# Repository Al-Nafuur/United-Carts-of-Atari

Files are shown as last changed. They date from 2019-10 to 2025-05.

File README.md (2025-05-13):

# Atari 2600 PlusCart

## Description
the Atari 2600 PlusCart ist based on Robin Edwards Unocart-2600 (https://github.com/robinhedwards/UnoCart-2600) and the extensions of Christian Speckner's (DirtyHairy) fork (https://github.com/DirtyHairy/UnoCart-2600). The PlusCart has no SD-Card, but an ESP8266 to connect to a local WiFi Network and the Internet.
The PlusCart downloads the ROM-files from an Server in the Internet called the "PlusStore". The way this is done is similar to the way the Unocart-2600 loads ROMs from the FAT filesystem on the SD-card, while the VCS is performing a waitroutine in his RAM.

## PlusROM
Additionally the PlusCart has one more interesting feature. It offers **internet access** to the ROM Developers, these functions are called "[PlusROM](http://pcart.firmaplus.de/pico/?PlusROM)". Examples for PlusROMs can be found in the [PlusROM-Hacks Repository](https://github.com/Al-Nafuur/PlusROM-Hacks) on Github.

## [Documentation](http://pcart.firmaplus.de/pico/)
More information and documentation can be found at the [PlusCart website](http://pcart.firmaplus.de/pico/)

Copyright:

(c) Firmaplus(+) Ltd.

Dipl.Ing.(FH) Wolfgang Stubig

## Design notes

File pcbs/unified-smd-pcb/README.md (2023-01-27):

Unified PlusCart UnoCart SMD PCB
===============

based on Randy Glenn's Unocart2600 PCB 
https://github.com/rglenn/unocart2600-pcb

migrated to KiCAD 6 and PlusCart WiFi module ESP8266 added by Wolfgang Stubig

Licensed under CERN OHL 1.2. See LICENSE.txt for more information.

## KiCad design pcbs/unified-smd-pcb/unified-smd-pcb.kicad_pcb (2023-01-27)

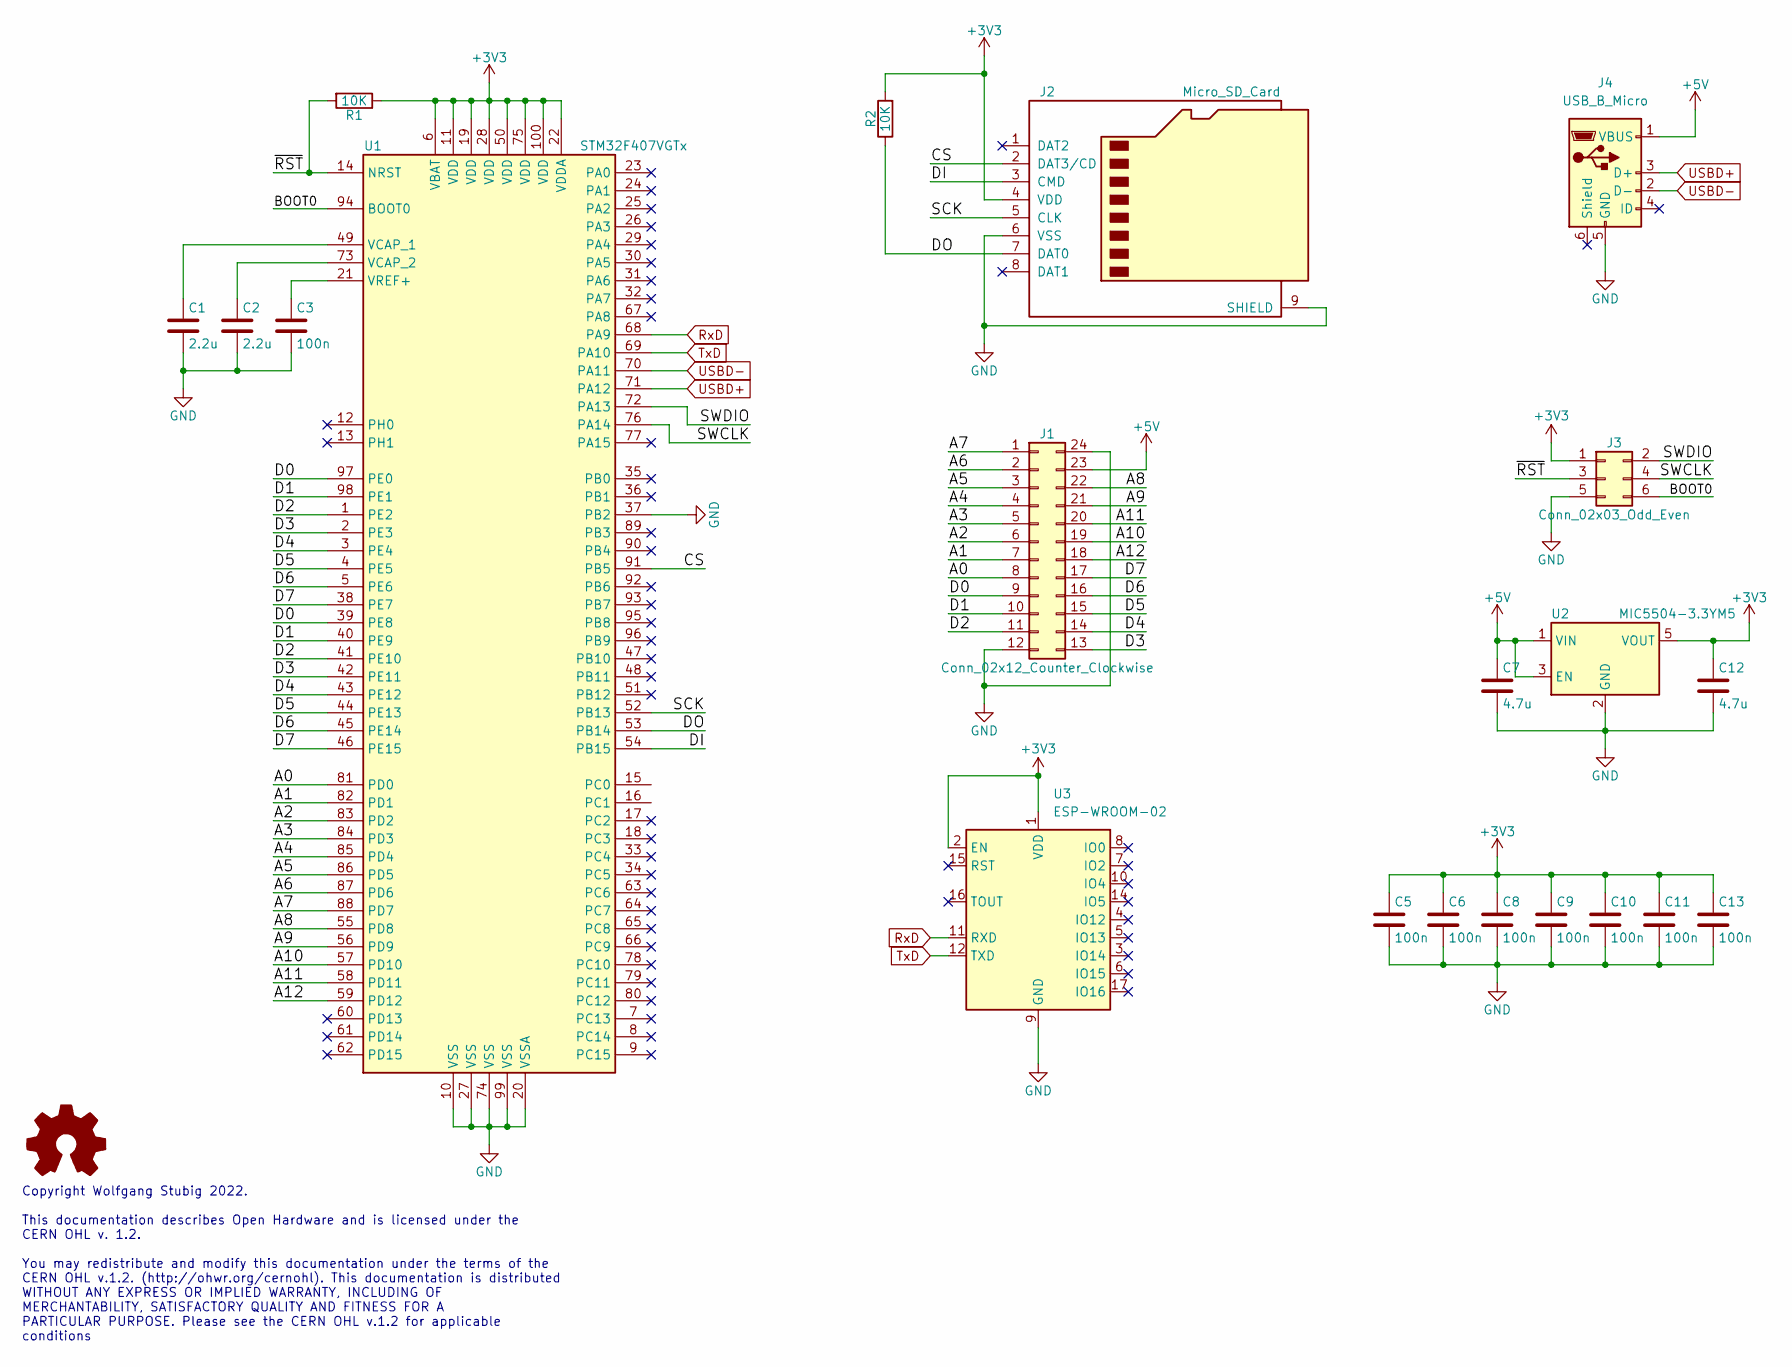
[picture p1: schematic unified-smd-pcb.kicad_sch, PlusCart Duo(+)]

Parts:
C1, C2: 2.2u; C_0603_1608Metric
C3, C5, C6, C8, C9, C10, C11, C13: 100n; C_0603_1608Metric
C7, C12: 4.7u; C_0805_2012Metric
J1: Conn_02x12_Counter_Clockwise; 2600-CARTRIDGE
J2: Micro_SD_Card; microSD_HRO_TF_01A
J3: Conn_02x03_Odd_Even; Tag-Connect_TC2030-IDC-NL_2x03_P1.27mm_Vertical
J4: USB_B_Micro; USB_Micro-B_Molex_47346-0001
R1, R2: 10K; R_0603_1608Metric
U1: STM32F407VGTx; LQFP-100_14x14mm_P0.5mm
U2: MIC5504-3.3YM5; SOT-23-5
U3: ESP-WROOM-02

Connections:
+3V3: C5.1, C6.1, C8.1, C9.1, C10.1, C11.1, C12.1, C13.1, J2.4 (VDD), J3.1, R1.1, R2.2, U1.6 (VBAT), U1.11 (VDD), U1.19 (VDD), U1.22 (VDDA), U1.28 (VDD), U1.50 (VDD), U1.75 (VDD), U1.100 (VDD), U2.5 (VOUT), U3.1 (VDD), U3.2 (EN)
+5V: C7.1, J1.23, J4.1 (VBUS), U2.1 (VIN), U2.3 (EN)
/A0: J1.8, U1.81 (PD0)
/A1: J1.7, U1.82 (PD1)
/A2: J1.6, U1.83 (PD2)
/A3: J1.5, U1.84 (PD3)
/A4: J1.4, U1.85 (PD4)
/A5: J1.3, U1.86 (PD5)
/A6: J1.2, U1.87 (PD6)
/A7: J1.1, U1.88 (PD7)
/A8: J1.22, U1.55 (PD8)
/A9: J1.21, U1.56 (PD9)
/A10: J1.19, U1.57 (PD10)
/A11: J1.20, U1.58 (PD11)
/A12: J1.18, U1.59 (PD12)
/BOOT0: J3.6, U1.94 (BOOT0)
/CS: J2.2 (DAT3/CD), U1.91 (PB5)
/D0: J1.9, U1.39 (PE8), U1.97 (PE0)
/D1: J1.10, U1.40 (PE9), U1.98 (PE1)
/D2: J1.11, U1.1 (PE2), U1.41 (PE10)
/D3: J1.13, U1.2 (PE3), U1.42 (PE11)
/D4: J1.14, U1.3 (PE4), U1.43 (PE12)
/D5: J1.15, U1.4 (PE5), U1.44 (PE13)
/D6: J1.16, U1.5 (PE6), U1.45 (PE14)
/D7: J1.17, U1.38 (PE7), U1.46 (PE15)
/DI: J2.3 (CMD), U1.54 (PB15)
/DO: J2.7 (DAT0), R2.1, U1.53 (PB14)
/SCK: J2.5 (CLK), U1.52 (PB13)
/SWCLK: J3.4, U1.76 (PA14)
/SWDIO: J3.2, U1.72 (PA13)
/~RST: J3.3, R1.2, U1.14 (NRST)
GND: C1.2, C2.2, C3.2, C5.2, C6.2, C7.2, C8.2, C9.2, C10.2, C11.2, C12.2, C13.2, J1.12, J1.24, J2.6 (VSS), J2.9 (SHIELD), J3.5, J4.5 (GND), U1.10 (VSS), U1.20 (VSSA), U1.27 (VSS), U1.37 (PB2), U1.74 (VSS), U1.99 (VSS), U2.2 (GND), U3.9 (GND), U3.13 (GND), U3.18 (GND), U3.19 (GND)
unnamed: C1.1, U1.49 (VCAP_1)
unnamed: C2.1, U1.73 (VCAP_2)
unnamed: C3.1, U1.21 (VREF+)
RxD: U1.68 (PA9), U3.11 (RXD)
TxD: U1.69 (PA10), U3.12 (TXD)
USBD+: J4.3 (D+), U1.71 (PA12)
USBD-: J4.2 (D-), U1.70 (PA11)

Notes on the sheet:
Copyright Wolfgang Stubig 2022. This documentation describes Open Hardware and is licensed under the CERN OHL v. 1.2. You may redistribute and modify this documentation under the terms of the CERN OHL v.1.2. (http://ohwr.org/cernohl). This documentation is distributed WITHOUT ANY EXPRESS OR IMPLIED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

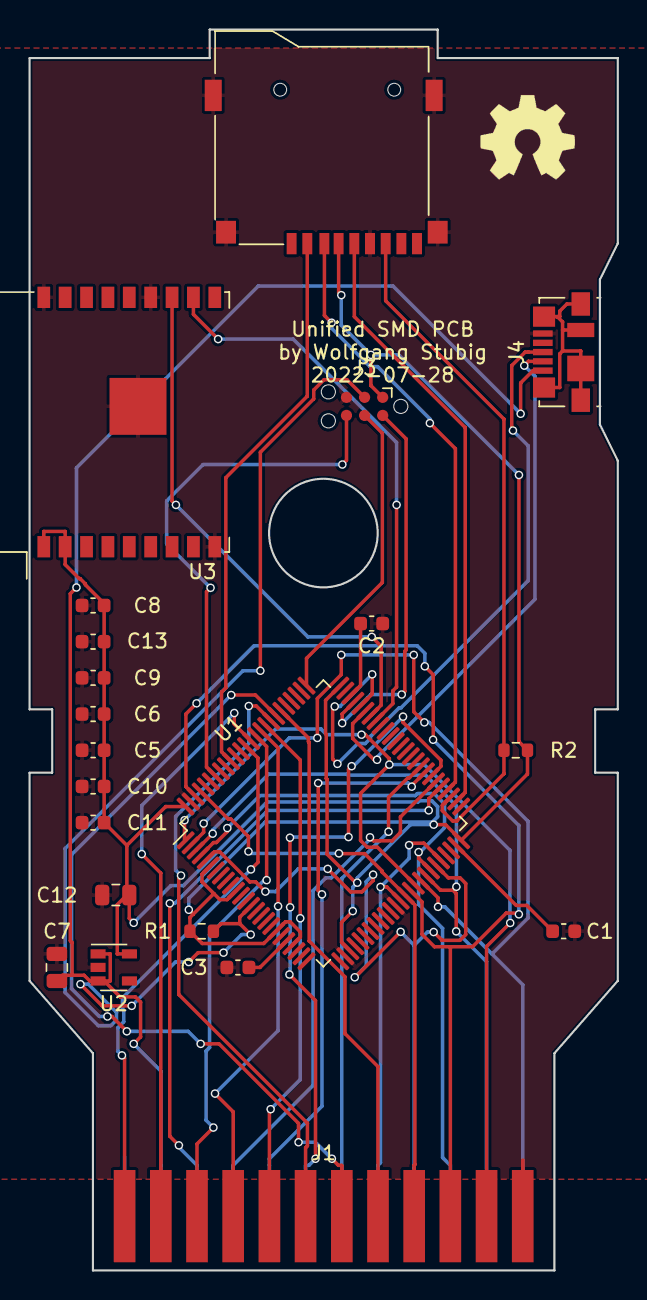
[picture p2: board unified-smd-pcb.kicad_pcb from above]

Board: 2 copper layers, 41.3 x 87.1 mm, 21 parts (0 on the bottom side), 39 nets.

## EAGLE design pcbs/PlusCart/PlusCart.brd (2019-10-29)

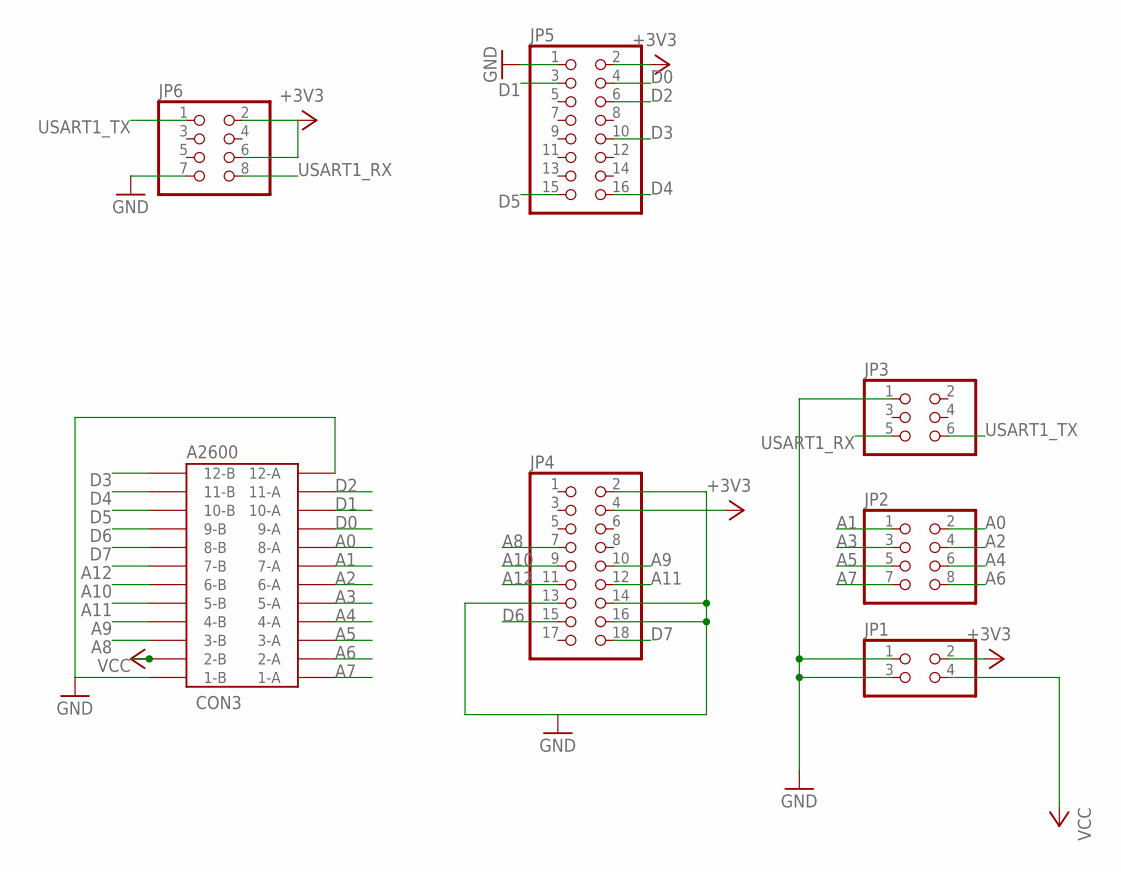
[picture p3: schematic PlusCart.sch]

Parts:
CON3: A2600; 24PINEDGE-254MM
JP1: PINHD-2X2; 2X02
JP2, JP6: PINHD-2X4; 2X04
JP3: PINHD-2X3; 2X03
JP4: PINHD-2X9; 2X09
JP5: PINHD-2X8; 2X08

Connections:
+3V3: JP1.2, JP4.4, JP5.2, JP6.2, JP6.6
A0: CON3.8-A, JP2.2
A1: CON3.7-A, JP2.1
A2: CON3.6-A, JP2.4
A3: CON3.5-A, JP2.3
A4: CON3.4-A, JP2.6
A5: CON3.3-A, JP2.5
A6: CON3.2-A, JP2.8
A7: CON3.1-A, JP2.7
A8: CON3.3-B, JP4.7
A9: CON3.4-B, JP4.10
A10: CON3.6-B, JP4.9
A11: CON3.5-B, JP4.12
A12: CON3.7-B, JP4.11
D0: CON3.9-A, JP5.4
D1: CON3.10-A, JP5.3
D2: CON3.11-A, JP5.6
D3: CON3.12-B, JP5.10
D4: CON3.11-B, JP5.16
D5: CON3.10-B, JP5.15
D6: CON3.9-B, JP4.15
D7: CON3.8-B, JP4.18
GND: CON3.1-B, CON3.12-A, JP1.1, JP1.3, JP3.1, JP4.2, JP4.13, JP4.14, JP4.16, JP5.1, JP6.7
USART1_RX: JP3.5, JP6.8
USART1_TX: JP3.6, JP6.1
VCC: CON3.2-B, JP1.4

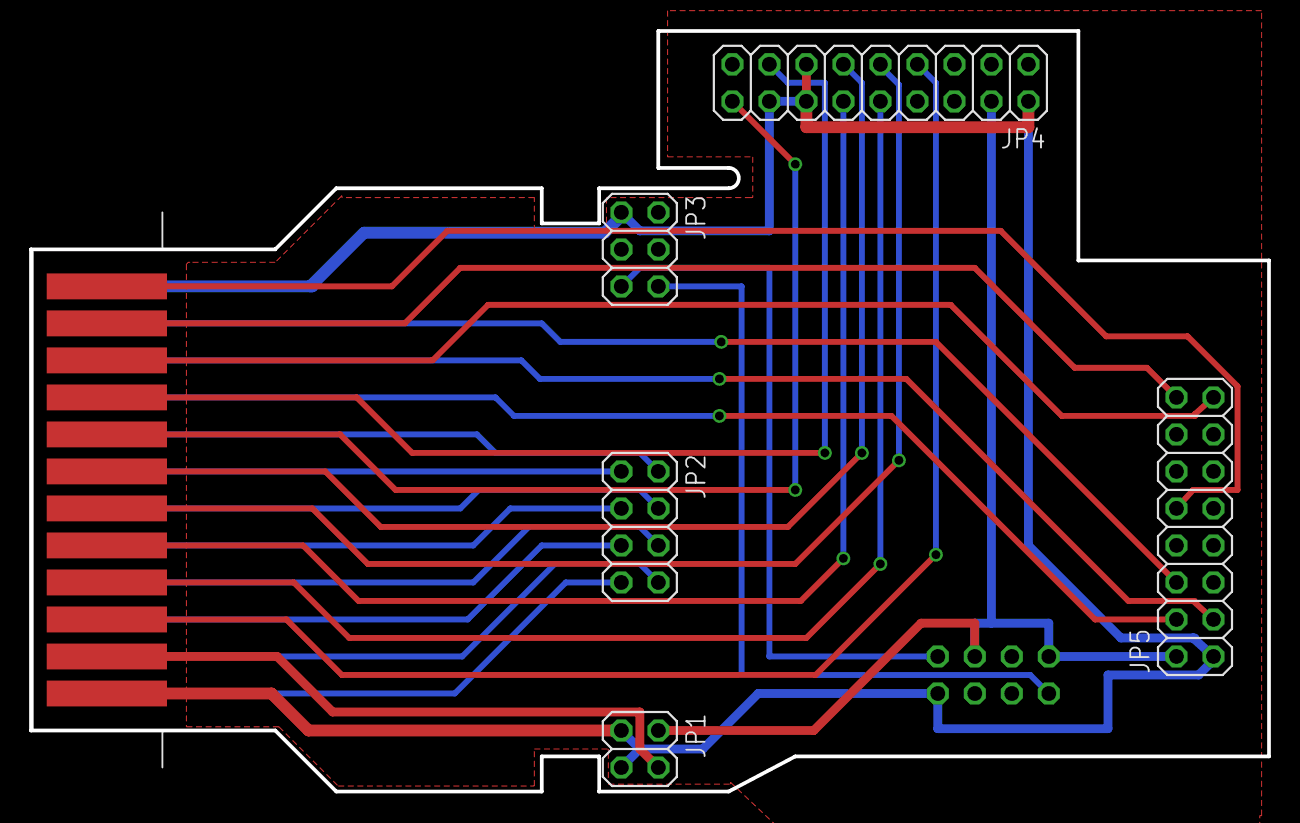
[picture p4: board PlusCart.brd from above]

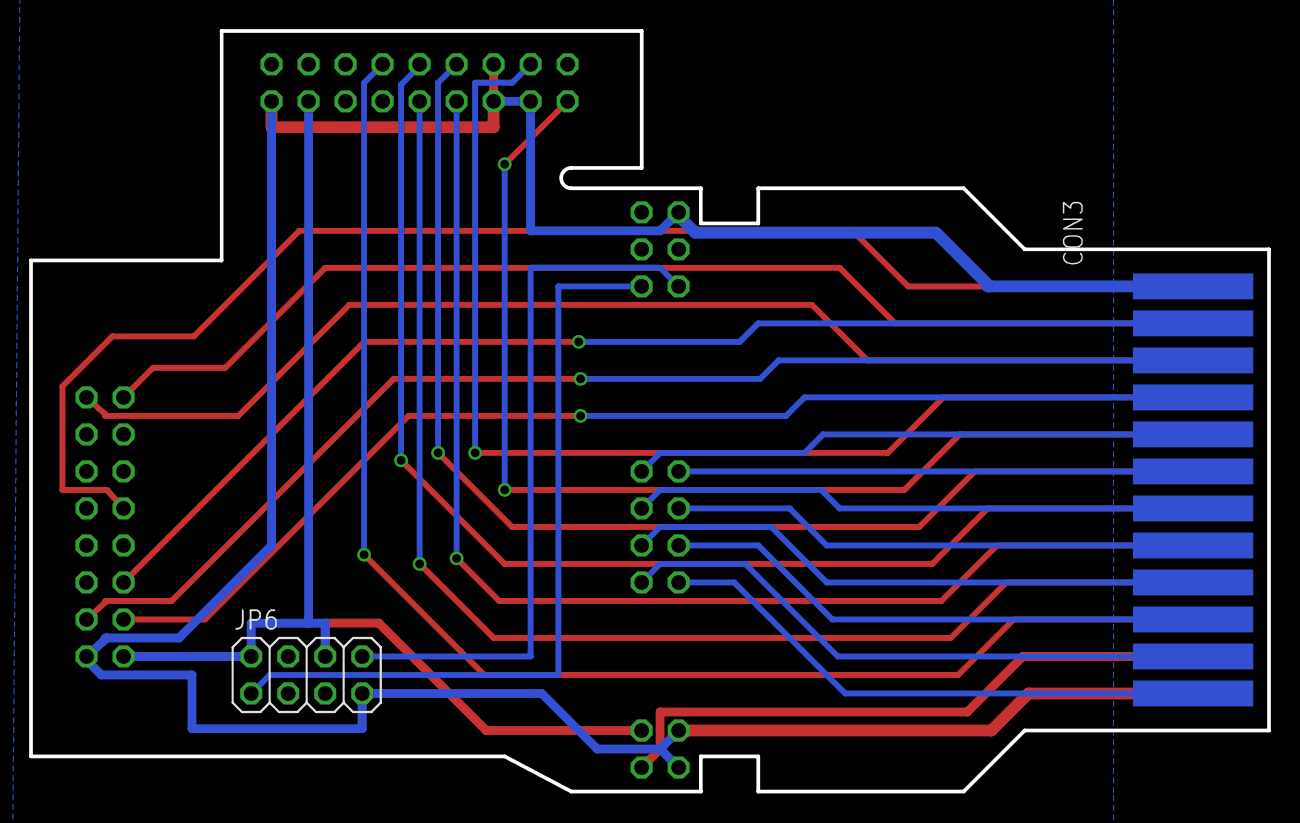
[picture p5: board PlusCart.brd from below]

Board: 2 copper layers, 85.0 x 52.2 mm, 7 parts (2 on the bottom side), 26 nets.

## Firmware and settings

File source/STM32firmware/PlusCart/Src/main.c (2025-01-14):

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
/* Includes ------------------------------------------------------------------*/
#include "main.h"

/* USER CODE BEGIN Includes */
#include <stdlib.h>
#include <stdio.h>
#include <ctype.h>
#include <string.h>

#include "global.h"
#include "font.h"
#if USE_WIFI
#include "esp8266.h"
#endif
#if USE_SD_CARD
#include "fatfs.h"
#endif

#include "stm32_udid.h"
#include "flash.h"
#include "cartridge_io.h"
#include "cartridge_firmware.h"
#include "cartridge_emulation_ACE.h"
#include "cartridge_emulation_ar.h"
#include "cartridge_emulation_ELF.h"
#include "cartridge_detection.h"
#include "cartridge_emulation.h"
#include "cartridge_emulation_df.h"
#include "cartridge_emulation_bf.h"
#include "cartridge_emulation_sb.h"
#include "cartridge_emulation_3F.h"


void generate_udid_string(void);

void truncate_curPath(/*uint8_t count*/);

/* USER CODE END Includes */

/* USER CODE BEGIN PTD */

typedef struct {
	enum cart_base_type base_type;
	bool withSuperChip;
	bool withPlusFunctions;
	bool uses_ccmram;
	bool uses_systick;
	uint32_t flash_part_address;
} CART_TYPE;

typedef struct {
	const char *ext;
	CART_TYPE cart_type;
} EXT_TO_CART_TYPE_MAP;

/* USER CODE END PTD */

/* USER CODE BEGIN PD */

const EXT_TO_CART_TYPE_MAP ext_to_cart_type_map[]__attribute__((section(".flash01"))) = {
	{"ROM",  { base_type_None,    false, false, false, false }},
	{"BIN",  { base_type_None,    false, false, false, false }},
	{"A26",  { base_type_None,    false, false, false, false }},
	{"2K",   { base_type_2K,      false, false, false, false }},
	{"4K",   { base_type_4K,      false, false, false, false }},
	{"4KS",  { base_type_4K,      true,  false, false, false }},
	{"F8",   { base_type_F8,      false, false, false, false }},
	{"F6",   { base_type_F6,      false, false, false, false }},
	{"F4",   { base_type_F4,      false, false, false, false }},
	{"F8S",  { base_type_F8,      true,  false, false, false }},
	{"F6S",  { base_type_F6,      true,  false, false, false }},
	{"F4S",  { base_type_F4,      true,  false, false, false }},
	{"FE",   { base_type_FE,      false, false, false, false }},
	{"3F",   { base_type_3F,      false, false, false, false }},
	{"3E",   { base_type_3E,      false, false, false, false }},
	{"E0",   { base_type_E0,      false, false, false, false }},
	{"084",  { base_type_0840,    false, false, false, false }},
	{"CV",   { base_type_CV,      false, false, false, false }},
	{"EF",   { base_type_EF,      false, false, false, false }},
	{"EFS",  { base_type_EF,      true,  false, false, false }},
	{"F0",   { base_type_F0,      false, false, false, false }},
	{"FA",   { base_type_FA,      false, false, false, false }},
	{"FA2",  { base_type_FA2,     false, false, false, false }},
	{"E7",   { base_type_E7,      false, false, false, false }},
	{"DPC",  { base_type_DPC,     false, false, true,  true  }},
	{"AR",   { base_type_AR,      false, false, false, false }},
	{"BF",   { base_type_BF,      false, false, true,  false }},
	{"BFS",  { base_type_BFSC,    false, false, true,  false }},
	{"ACE",  { base_type_ACE,     false, false, false, false }},
	{"WD",   { base_type_PP,      false, false, false, false }},
	{"DF",   { base_type_DF,      false, false, true,  false }},
	{"DFS",  { base_type_DFSC,    false, false, true,  false }},
	{"3EP",  { base_type_3EPlus,  false, false, false, false }},
	{"DPCP", { base_type_DPCplus, false, false, false, true  }},
	{"SB",   { base_type_SB,      false, false, true,  false }},
	{"UA",   { base_type_UA,      false, false, false, false }},
	{"ELF",  { base_type_ELF,     false, false, false, false }},

	{0,{0,0,0}}
};

const char *status_message[]__attribute__((section(".flash01#"))) = {

#if MENU_TYPE == UNOCART
	"UnoCart 2600",
#else
	"PlusCart(+)",
#endif
	"Select WiFi Network",
	"No WiFi",
	"WiFi connected",
	"Request timeout",
	"Enter WiFi Password",
	"Enter email or username",
	"Your Chat Message",
	"Offline ROMs erased",
	"ROM file too big!",
	"ACE file unsupported",
	"Unknown/invalid ROM",
	"Done",
	"Failed",
	"Firmware download failed",
	"Offline ROMs detected",
	"No offline ROMs detected",
	"DPC+ is not supported",
	"Emulation exited",
	"ROM Download Failed",

	"Setup",
	"Select TV Mode",
	"Select Font",
	"Select Line Spacing",
	"Setup/System Info",
	MENU_TEXT_SEARCH_FOR_ROM,
	"Enter search details",
	"Search results",
	"Host name or IP address",

//	MENU_TEXT_APPEARANCE,
};

const uint8_t numMenuItemsPerPage[] = {
		// ref: SPACING enum
		14,									// dense
		12,									// medium
		10									// sparse
};

//
/* USER CODE END PD */

#if USE_SD_CARD
SPI_HandleTypeDef hspi2;
#endif
#if USE_WIFI
UART_HandleTypeDef huart1;
#endif

/* USER CODE BEGIN PV */
int num_menu_entries = 0;
char http_request_header[512] __attribute__ ((section (".noinit")));

char stm32_udid[25];


uint8_t buffer[BUFFER_SIZE * 1024] __attribute__((section(".buffer")));
unsigned int cart_size_bytes;

USER_SETTINGS user_settings;

char curPath[256] __attribute__ ((section (".noinit")));
char input_field[STATUS_MESSAGE_LENGTH] __attribute__ ((section (".noinit")));

int inputActive __attribute__ ((section (".noinit")));

uint8_t plus_store_status[1];

MENU_ENTRY menu_entries[NUM_MENU_ITEMS] __attribute__((section(".ccmram")));


/* USER CODE END PV */

void SystemClock_Config(void);
static void MX_GPIO_Init(void);
#if USE_WIFI
static void MX_USART1_UART_Init(void);
#endif
#if USE_SD_CARD
static void MX_SPI2_Init(void);
#endif
/* USER CODE BEGIN PFP */
enum e_status_message buildMenuFromPath( MENU_ENTRY * )__attribute__((section(".flash0"))) ;
void append_entry_to_path(MENU_ENTRY *);



/* USER CODE END PFP */

/* USER CODE BEGIN 0 */


void generate_udid_string(){
	int i;
	uint8_t c;
	memset(stm32_udid, '0', 24);
	stm32_udid[24] = '\0';
	for (int j = 2; j > -1; j--){
		uint32_t content_len = STM32_UDID[j];
		i = (j * 8) + 7;
		while (content_len != 0 && i > -1) {
			c = content_len % 16;
			stm32_udid[i--] = (char)((c > 9)? (c-10) + 'a' : c + '0');
			content_len = content_len/16;
		}
	}
}


/*************************************************************************
 * Menu Handling
 *************************************************************************/

char *get_filename_ext(char *filename) {
	char *dot = strrchr(filename, '.');
	if(!dot || dot == filename) return "";
	return (dot + 1);
}

/*inline*/ void make_menu_entry_font( MENU_ENTRY **dst, const char *name, int type, uint8_t font) {
	(*dst)->type = type;
	strcpy((*dst)->entryname, name);
	(*dst)->filesize = 0U;
	(*dst)->font = font;
	(*dst)++;
	num_menu_entries++;
}

void make_menu_entry( MENU_ENTRY **dst, const char *name, int type){
	make_menu_entry_font(dst, name, type, user_settings.font_style);
}


const char *keyboardUppercase[]__attribute__((section(".flash0#"))) = {
	" 1  2  3  4  5  6  7  8  9  0",
	"  Q  W  E  R  T  Y  U  I  O  P",
	"   A  S  D  F  G  H  J  K  L",
	"    Z  X  C  V  B  N  M",
	"     " MENU_TEXT_SPACE " !  ?  ,  .",
	0
};

const char *keyboardLowercase[]__attribute__((section(".flash0#"))) = {
	" 1  2  3  4  5  6  7  8  9  0",
	"  q  w  e  r  t  y  u  i  o  p",
	"   a  s  d  f  g  h  j  k  l",
	"    z  x  c  v  b  n  m",
	"     " MENU_TEXT_SPACE " !  ?  ,  .",
	0
};

const char *keyboardSymbols[]__attribute__((section(".flash0#"))) = {
	" " MENU_TEXT_SPACE "   ( )  { }  [ ]  < >",
	"  !  ?  .  ,  :  ;  \"  '  `",
	"   @  ^  |  \\  ~  #  $  %  &",
	"    +  -  *  /  =  _",
	0
};


enum keyboardType {
	KEYBOARD_UPPERCASE,
	KEYBOARD_LOWERCASE,
	KEYBOARD_SYMBOLS,
	KEYBOARD_NONE,
};

static const char **keyboards[]__attribute__((section(".flash0#"))) = {
	keyboardUppercase,
	keyboardLowercase,
	keyboardSymbols,
	0
};


enum keyboardType lastKb = KEYBOARD_UPPERCASE;

int compVersions ( const char * version1, const char * version2 ) {
    unsigned major1 = 0, minor1 = 0, bugfix1 = 0;
    unsigned major2 = 0, minor2 = 0, bugfix2 = 0;
    sscanf(version1, "%u.%u.%u", &major1, &minor1, &bugfix1);
    sscanf(version2, "%u.%u.%u", &major2, &minor2, &bugfix2);
    if (major1 < major2) return -1;
    if (major1 > major2) return 1;
    if (minor1 < minor2) return -1;
    if (minor1 > minor2) return 1;
    if (bugfix1 < bugfix2) return -1;
    if (bugfix1 > bugfix2) return 1;
    return 0;
}

void make_keyboardFromLine(MENU_ENTRY **dst, char *line) {

	make_menu_entry(dst, MENU_TEXT_GO_BACK, Leave_SubKeyboard_Menu);
	char item[33];
	while (*line) {
		char *entry = item;
		while (*line && *line == ' ')
			line++;
		while (*line && *line != ' ')
			*entry++ = *line++;
		*entry = 0;
		if (*item)
			make_menu_entry(dst, item, Keyboard_Char);
	}
}


void make_keyboard(MENU_ENTRY **dst, enum keyboardType selector){

	make_menu_entry(dst, MENU_TEXT_GO_BACK, Leave_Menu);

	for (const char **kbRow = keyboards[selector]; *kbRow; kbRow++)
		make_menu_entry(dst, *kbRow, Keyboard_Row);

	if (selector != KEYBOARD_LOWERCASE)
		make_menu_entry(dst, MENU_TEXT_LOWERCASE, Keyboard_Row);
	if (selector != KEYBOARD_UPPERCASE)
		make_menu_entry(dst, MENU_TEXT_UPPERCASE, Keyboard_Row);
	if (selector != KEYBOARD_SYMBOLS)
		make_menu_entry(dst, MENU_TEXT_SYMBOLS, Keyboard_Row);

	if (*input_field)
		make_menu_entry(dst, MENU_TEXT_DELETE_CHAR, Delete_Keyboard_Char);

	make_menu_entry(dst, "Enter", Menu_Action);
}

/*
MENU_ENTRY *generateAppearanceMenu(MENU_ENTRY *dst) {
	make_menu_entry(&dst, MENU_TEXT_GO_BACK, Leave_Menu);
	make_menu_entry(&dst, MENU_TEXT_TV_MODE_SETUP, Setup_Menu);
	make_menu_entry(&dst, MENU_TEXT_FONT_SETUP, Setup_Menu);
	make_menu_entry(&dst, MENU_TEXT_SPACING_SETUP, Setup_Menu);
	return dst;
}*/


MENU_ENTRY* generateSetupMenu(MENU_ENTRY *dst) {
	make_menu_entry(&dst, MENU_TEXT_GO_BACK, Leave_Menu);
#if USE_WIFI
	make_menu_entry(&dst, MENU_TEXT_WIFI_SETUP, Setup_Menu);
	make_menu_entry(&dst, MENU_TEXT_API_HOST, Input_Field);
#endif
	make_menu_entry(&dst, MENU_TEXT_DISPLAY, Setup_Menu);
	make_menu_entry(&dst, MENU_TEXT_SYSTEM_INFO, Sub_Menu);

	if (flash_has_downloaded_roms())
		make_menu_entry(&dst, MENU_TEXT_DELETE_OFFLINE_ROMS, Menu_Action);
	else
		make_menu_entry(&dst, MENU_TEXT_DETECT_OFFLINE_ROMS, Menu_Action);
	make_menu_entry(&dst, MENU_TEXT_FORMAT_EEPROM, Menu_Action);
	if (EXIT_SWCHB_ADDR == SWCHB)
		make_menu_entry(&dst, MENU_TEXT_DISABLE_EMU_EXIT, Menu_Action);
	else
		make_menu_entry(&dst, MENU_TEXT_ENABLE_EMU_EXIT, Menu_Action);

	return dst;
}

MENU_ENTRY* generateSystemInfo(MENU_ENTRY *dst) {
#if MENU_TYPE == PLUSCART
	make_menu_entry(&dst, "PlusCart Device ID", Leave_Menu);
#elif MENU_TYPE == UNOCART
	make_menu_entry(&dst, "UnoCart Device ID", Leave_Menu);
#endif

	sprintf(input_field, "        %s", stm32_udid);
	make_menu_entry(&dst, input_field, Leave_Menu);

	make_menu_entry(&dst, "STM Firmware       "VERSION, Leave_Menu);

#if USE_WIFI
	sprintf(input_field, "WiFi Firmware      %s", esp8266_at_version);
	make_menu_entry(&dst, input_field, Leave_Menu);
	make_menu_entry(&dst, "API Host", Leave_Menu);
	sprintf(input_field, "  %s", user_settings.api_host);
	make_menu_entry(&dst, input_field, Leave_Menu);
#endif

	sprintf(input_field, "Flash Size         %s", STM32F4_FLASH_SIZE > 512U ? "1 MiB": "512 KiB");
	make_menu_entry(&dst, input_field, Leave_Menu);


	sprintf(input_field, "Flash Used         %d KiB", (user_settings.first_free_flash_sector - 4 ) * 128);
	make_menu_entry(&dst, input_field, Leave_Menu);

#if USE_SD_CARD
	int * sd_stat = sd_card_statistic();
   	sprintf(input_field, "SD-Card Size       %d MiB", sd_stat[sd_card_total_size] );
   	make_menu_entry(&dst, input_field, Leave_Menu);
   	sprintf(input_field, "SD-Card Used       %d MiB", sd_stat[sd_card_used_size] );
   	make_menu_entry(&dst, input_field, Leave_Menu);
#endif

	*input_field = 0;
	return dst;
}

enum e_status_message generateKeyboard(
		MENU_ENTRY **dst,
		MENU_ENTRY *d,
		enum e_status_message menuStatusMessage,
		enum e_status_message new_status) {

	// Scan for any keyboard rows, and if found then generate menu for row
	for (const char ***kb = keyboards; *kb; kb++)
		for (const char **row = *kb; *row; row++)
			if (!strcmp(*row, d->entryname)) {
				make_keyboardFromLine(dst, d->entryname);
				truncate_curPath();
				return menuStatusMessage;
			}

	// look for change of keyboard
	if (!strcmp(d->entryname, MENU_TEXT_LOWERCASE))
		lastKb = KEYBOARD_LOWERCASE;
	else if (!strcmp(d->entryname, MENU_TEXT_UPPERCASE))
		lastKb = KEYBOARD_UPPERCASE;
	else if (!strcmp(d->entryname, MENU_TEXT_SYMBOLS))
		lastKb = KEYBOARD_SYMBOLS;
	else {

		// initial case - use previous keyboard
		menuStatusMessage = new_status;
		strcat(curPath, "/");				// trimmed off, below
	}

	make_keyboard(dst, lastKb);
	truncate_curPath();
	return menuStatusMessage;
}

int entry_compare(const void* p1, const void* p2){
	MENU_ENTRY* e1 = (MENU_ENTRY*)p1;
	MENU_ENTRY* e2 = (MENU_ENTRY*)p2;
	if (e1->type == Leave_Menu) return -1;
	else if (e2->type == Leave_Menu) return 1;
	else if (e1->type == SD_Sub_Menu && e2->type != SD_Sub_Menu) return -1;
	else if (e1->type != SD_Sub_Menu && e2->type == SD_Sub_Menu) return 1;
	else return strcasecmp(e1->entryname, e2->entryname);
}

enum e_status_message buildMenuFromPath( MENU_ENTRY *d )  {
	bool loadStore = false; // ToDo rename to loadPath (could be SD, flash or WiFi path)
	num_menu_entries = 0;
	enum e_status_message menuStatusMessage = STATUS_NONE;

	char *menuFontNames[] = {
			// same ordering as font IDs
			MENU_TEXT_FONT_TJZ,
			MENU_TEXT_FONT_TRICHOTOMIC12,
			MENU_TEXT_FONT_CAPTAIN_MORGAN_SPICE,
			MENU_TEXT_FONT_GLACIER_BELLE
	};

	char *tvModes[] = {
			0,
			MENU_TEXT_TV_MODE_NTSC,		// -->1
			MENU_TEXT_TV_MODE_PAL,		// -->2
			MENU_TEXT_TV_MODE_PAL60,	// -->3
	};

	char *spacingModes[] = {
			MENU_TEXT_SPACING_DENSE,		// referenced by SPACING enum
			MENU_TEXT_SPACING_MEDIUM,
			MENU_TEXT_SPACING_SPARSE,
	};


	MENU_ENTRY *dst = (MENU_ENTRY *)&menu_entries[0];
		// and this caters for the trailing slash in the setup string (if present)
//	char *mtsap = mts + sizeof(MENU_TEXT_APPEARANCE);

	if (d->type == Input_Field || d->type == Keyboard_Char || d->type == Keyboard_Row ||
			d->type == Delete_Keyboard_Char || d->type == Leave_SubKeyboard_Menu ){
		// toDo  Input_Field to Leave_SubKeyboard_Menu consecutive!
		int new_status = 1;
		if (strstr(curPath, MENU_TEXT_SEARCH_FOR_ROM) == curPath){
		    new_status = STATUS_SEARCH_DETAILS;
		}else{  // All Setup menu stuff here!
			char *mts = curPath + sizeof(MENU_TEXT_SETUP);   // does a +1 because of MENU_TEXT_SETUP trailing 0
		    if(strstr(mts, MENU_TEXT_PLUS_CONNECT) == mts)
		        new_status = plus_connect;
		    else if(strstr(mts, MENU_TEXT_WIFI_SETUP) == mts)
		        new_status = insert_password;
		    else if(strstr(mts, MENU_TEXT_API_HOST) == mts)
		        new_status = STATUS_HOST_OR_IP;
		    else
		        new_status = STATUS_YOUR_MESSAGE;
		}
		if (d->type == Input_Field)
			*input_field = 0;

		menuStatusMessage = generateKeyboard(&dst, d, menuStatusMessage, new_status);
	}
	else if(strstr(curPath, MENU_TEXT_SETUP) == curPath) {
		char *mts = curPath + sizeof(MENU_TEXT_SETUP);   // does a +1 because of MENU_TEXT_SETUP trailing 0

		if (!strcmp(curPath, MENU_TEXT_SETUP)){
			menuStatusMessage = STATUS_SETUP;
			dst = generateSetupMenu(dst);
			loadStore = true;
		}

//		else if (strstr(mts, MENU_TEXT_APPEARANCE) == mts) {
//			dst = generateAppearanceMenu(dst);
//			loadStore = true;
//		}

		else if (strstr(mts, URLENCODE_MENU_TEXT_SYSTEM_INFO) == mts) {
			menuStatusMessage = STATUS_SETUP_SYSTEM_INFO;
			dst = generateSystemInfo(dst);
			loadStore = true;
		}
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
int main(void)
{
  /* USER CODE BEGIN 1 */

	uint8_t act_page = 0;
    MENU_ENTRY *d = &menu_entries[0];

  /* USER CODE END 1 */

  /* MCU Configuration--------------------------------------------------------*/

  /* Reset of all peripherals, Initializes the Flash interface and the Systick. */
  HAL_Init();

  /* Configure the system clock */
  SystemClock_Config();

  /* Initialize all configured peripherals */
  MX_GPIO_Init();
  /* USER CODE BEGIN 2 */

  user_settings = flash_get_eeprom_user_settings();
  set_tv_mode(user_settings.tv_mode);

  /* USER CODE END 2 */

  /* Infinite loop */
  /* USER CODE BEGIN WHILE */
  enum e_status_message menuStatusMessage = STATUS_ROOT; //, main_status = none;
  while (1)
  {
    /* USER CODE END WHILE */

    /* USER CODE BEGIN 3 */
	    int ret = emulate_firmware_cartridge();

		if (ret == CART_CMD_ROOT_DIR) {
			system_secondary_init();

			d->type = Root_Menu;
			d->filesize = 0;

			*input_field = *curPath = 0;
			inputActive = 0;

			menuStatusMessage = buildMenuFromPath(d);
		}

		else if (ret == CART_CMD_PAGE_DOWN) {
			act_page--;
		}

		else if (ret == CART_CMD_PAGE_UP) {
			act_page++;
		}

		else {

			ret += act_page * numMenuItemsPerPage[user_settings.line_spacing];
			d = &menu_entries[ret];

			act_page = 0; // seems to fix the "blank" menus - because page # was not init'd on new menu

			if (d->type == Cart_File || d->type == Offline_Cart_File || d->type == SD_Cart_File) {

				// selection is a rom file
				int flash_sectors = (STM32F4_FLASH_SIZE > 512U) ? 12 : 8;
				int32_t max_romsize = (((BUFFER_SIZE + CCM_RAM_SIZE) * 1024)
						+ (flash_sectors - user_settings.first_free_flash_sector ) * 128 * 1024);
				if (d->filesize > max_romsize)
					menuStatusMessage = not_enough_menory;

				else {

					CART_TYPE cart_type = identify_cartridge(d);
					HAL_Delay(200);

					if (cart_type.base_type == base_type_ACE && !(is_ace_cartridge(d->filesize, buffer)))
						menuStatusMessage = romtype_ACE_unsupported;

					else if (cart_type.base_type == base_type_Load_Failed)
						menuStatusMessage = rom_download_failed;

					else if (cart_type.base_type == base_type_DPCplus)
						menuStatusMessage = romtype_DPCplus_unsupported;

					else if (cart_type.base_type != base_type_None) {

						emulate_cartridge(cart_type, d);
						set_menu_status_byte(STATUS_StatusByteReboot, 0);
						menuStatusMessage = exit_emulation;

						if(cart_type.uses_systick){
							SysTick_Config(SystemCoreClock / 1000U);	// 1KHz
						}
					}

					else
						menuStatusMessage = romtype_unknown;
				}

				truncate_curPath();

				d->type = Sub_Menu;
				buildMenuFromPath(d);

			}

			else {  // not a cart file...

				// selection is a directory or Menu_Action, or Keyboard_Char
				if (d->type == Leave_Menu) {

					inputActive++;
					while(inputActive--)
						truncate_curPath();

					inputActive = 0;
					*input_field = 0;
				}

				else if (d->type == Leave_SubKeyboard_Menu) {
				}

				else if (d->type == Delete_Keyboard_Char) {

					unsigned int len = strlen(input_field);
					if (len) {
						input_field[--len] = 0;
						curPath[strlen(curPath) - 1] = 0;
					}

				} else {

					if (d->type != Keyboard_Char && strlen(curPath) > 0 ) {
						strcat(curPath, "/");
					}
					else if (d->type == Keyboard_Char && !strcmp(d->entryname, MENU_TEXT_SPACE))
						strcpy(d->entryname, " ");

					append_entry_to_path(d);

					if (d->type == Keyboard_Char) {

						if (strlen(input_field) + strlen(d->entryname) < STATUS_MESSAGE_LENGTH - 1)
							strcat(input_field, d->entryname);

					}
					else if (d->type == Input_Field) {
						strcat(curPath, "/");
						inputActive++; // = 1 ???
					}
					else {
						if (d->type == Menu_Action) {
							if(inputActive)
								inputActive += 2; // input + "Enter", if input contains path_sep trim will be corrected by API
							*input_field = 0;
						}
					}
				}
				menuStatusMessage = buildMenuFromPath(d);
			}
		}


		if (*input_field || menuStatusMessage == STATUS_MESSAGE_STRING) {
			set_menu_status_msg(input_field);
			set_menu_status_byte(STATUS_PageType, (uint8_t) Keyboard);
		}

	    else {

	    	if (menuStatusMessage >= STATUS_ROOT)
	    		set_menu_status_msg(status_message[menuStatusMessage]);

	    	if(act_page > (num_menu_entries / numMenuItemsPerPage[user_settings.line_spacing]) )
	    		act_page = 0;

	    	set_menu_status_byte(STATUS_PageType, (uint8_t) Directory);
	    }
	#if USE_WIFI
		bool is_connected = esp8266_is_connected();
	#else
		bool is_connected = false;
	#endif
		createMenuForAtari(menu_entries, act_page, num_menu_entries, is_connected, plus_store_status );
	    HAL_Delay(200);
  }
  /* USER CODE END 3 */
}

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


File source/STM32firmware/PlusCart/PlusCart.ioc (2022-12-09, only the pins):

Mcu.UserName=STM32F407VGTx
PA10.Signal=USART1_RX
PA9.Signal=USART1_TX
PB13.Signal=SPI2_SCK
PB14.Signal=SPI2_MISO
PB15.Signal=SPI2_MOSI
PB5.GPIO_Label=SD_CS
PB5.Signal=GPIO_Output
PC0.Signal=GPIO_Input
PC1.Signal=GPIO_Input
PC14-OSC32_IN.Signal=RCC_OSC32_IN
PC15-OSC32_OUT.Signal=RCC_OSC32_OUT
PC2.Signal=GPIO_Input
PC3.Signal=GPIO_Input
PC4.Signal=GPIO_Input
PC5.Signal=GPIO_Input
PC6.Signal=GPIO_Input
PC7.Signal=GPIO_Input
PD0.Signal=GPIO_Input
PD1.Signal=GPIO_Input
PD10.Signal=GPIO_Input
PD11.Signal=GPIO_Input
PD12.Signal=GPIO_Input
PD13.Signal=GPIO_Input
PD14.Signal=GPIO_Input
PD15.Signal=GPIO_Input
PD2.Signal=GPIO_Input
PD3.Signal=GPIO_Input
PD4.Signal=GPIO_Input
PD5.Signal=GPIO_Input
PD6.Signal=GPIO_Input
PD7.Signal=GPIO_Input
PD8.Signal=GPIO_Input
PD9.Signal=GPIO_Input
PH0-OSC_IN.Signal=RCC_OSC_IN
PH1-OSC_OUT.Signal=RCC_OSC_OUT

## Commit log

2019-10-23 Add PCB for PlusCart breakout board V1
    [PlusCart.brd, PlusCart.sch]
2019-10-26 assembly images for Readme and docs
2019-10-26 update PCB and new Gerberfile
    [PlusCart.brd, PlusCart.sch]
2019-10-29 Breakoutboard optimization, new gerberfiles
    [PlusCart.brd, PlusCart.sch]
2019-11-01 add source for STM32 and Atari 2600
2019-11-22 bugfixes, Plus functions for 2K, process_transmission at A12 high
    [cartridge_emulation.c, main.c]
2019-11-29 new menu structur, fix australia timeout bug
    [main.c]
2019-12-28 improved menu, bugfix PlusStore disconnect
    [esp8266.c, global.h, main.c]
2019-12-29 bugfix FxSC cart writeToSendBuffer not working
    [cartridge_emulation.c, global.h]
2019-12-29 add River Raid HighScore ASM code and bugfix 2K, 4K writeToSendBuffer
    [cartridge_emulation.c, global.h]
2020-01-15 t-online.de NewsTicker PlusROM example
2020-01-31 Moved/reorganized flash related stuff to flash modul User settings in eeprom emulation flash sector 1 Bugfix for flashing ROM collections > 256 Kb Code cleanup
    [flash.c, global.h, main.c]
2020-02-01 bugfix range request wrong start point
    [esp8266.c]
2020-02-04 Bugfix and reorganization for DF, DFSC, BF and BFSC
    [cartridge_emulation.c, main.c]
2020-02-14 reworked esp8266 lib range requests wait for expected_size with 15s timeout, read Content-Lenght from response header, use Content-Length for menu loading also.
    [esp8266.c, global.h, main.c]
2020-02-20 fixed bug in last chunk size calculation tweak pause between requests
    [flash.c]
2020-02-25 bugfix timeout at PlusROM API connect
    [esp8266.c, global.h]
2020-03-01 Bugfix Supercharger multiload map request
    [global.h]
2020-03-02 fallback to prevent empty Menu or Dir
    [global.h, main.c]
2020-03-06 WPS (WiFi Protected Setup) Factory reset for ESP8266 auto detection and emulation for 6144 bytes Supercharger ROMs
    [esp8266.c, global.h, main.c]
2020-03-13 fix URI encode bug at Plus connect and Plus remove
    [esp8266.c, global.h, main.c]
2020-03-14 download firmware to RAM buffer and check size before flashing separate offline ROMs download from firmware download break after first faild chunk download (ROM or firmware)
    [esp8266.c, flash.c, global.h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]
2020-03-31 skip flashing user settings area
    [flash.c]
2020-03-31 move esp8266 functions to flash sector 0. Uninitialize stm32_udid and code optimization
2020-04-05 - new 32 char menu - status message redesign - skip downloading settings area at firmware update - status byte in response from PlusStore API
    [PlusCart.asm, global.h]
2020-04-09 bugfix downloading ROMs tar file for PlusStore API
    [flash.c, global.h, main.c]
2020-08-28 block menu after emulation exit until Joystick (or Paddle button) is released
2020-08-31 bugfix for menu responses larger than 9999 bytes
    [esp8266.c]
2020-09-08 Bugfix PlusROM backend connect
    [esp8266.c]
2020-09-11 switch to stdbool
2020-09-11 switch to stdbool and user selectable font
2020-09-11 64 RAM pages for 3E+ and switch to stdbool
2020-09-11 user selectable font and switch to stdbool
2020-09-12 use stdbool, bugfix eeprom emulation, tweak user_settings read/write
    [flash.c]
2020-09-20 Animated logo, increase MAX_RANGE_SIZE to 32768, Fixed exit function for ROMs larger than 96 KiB, DCP+ changed read DATA_IN, Captain Morgan Spiced Font, Trichotomic 12 tweaks, wordings changed
    [esp8266.c, esp8266_AT_WiFiManager.h, global.h]
2020-09-21 updated TV mode menu to show current selection
2020-09-21 font testbed now handles all fonts via switch (FONT) Note that these fonts are the MASTER definitions - change here first build and check on '2600/emulator. and then copy the font data to the firmwar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
2020-09-23 highlighted menu line now correct vertical size. more work to do....
    [main.c]
2020-10-07 fixed "go back" in keyboard submenus
    [global.h, main.c]
2020-10-09 removed wifi-related code identified as problematic
    [main.c]
2020-10-14 fixed keyboard for username/email entry in plusstore connect
    [main.c]
2020-11-02 fixed '7800 absolute load error/bug (menu paging) synched Atari2600ROM with STM code -- now identical 14-line menu now functional.
    Bugs: flickering menu selection bar
    - wifi symbol corrupted on 1st page
    [PlusCart.asm]
2020-11-02 fixed flashing menu selection bar/line
    [PlusCart.asm]
2020-11-02 bugfix, read a possibly existing close message from ESP8266 before starting a new request
    [esp8266.c]
2020-11-05 fixed wifi symbol corruption (was an off-by-one error)
    lots of changes to remove various compiler warnings.
    [flash.c, global.h, main.c]
2020-11-05 rounder brackets in Glacier Belle font
2020-11-06 Fix PlusROM and exit function in 3E and 3E+. Fixed source indentation
    [cartridge_emulation.c]
2020-11-10 display correct font for font menu selections
    [main.c]
2020-11-10 revert default font to Small Caps
    [flash.c]
2020-11-11 Bugfix downloaded ROM size check, new message for "ROM Download Failed"
    [global.h, main.c]
2020-11-13 add STM32CubeIDE language settings to gitignore
2020-11-18 rework of menu system
    * paging U/D/L/R function modified
    on a single page menu...
    UP will go to previous item on page
    DOWN will go to next item on page
    LEFT will go to top of page
    RIGHT will go to bottom of page
    on multi-page menus...
    UP will move up one item
    or if at top will go last item on previous page
    DOWN will move down one item
    or if at bottom will go to first item on next page
    LEFT will go to first item on previous page
    RIGHT will go to first item on next page
    [PlusCart.asm, global.h]
2020-11-18 fixed duplicate label error
    [PlusCart.asm]
2020-11-19 Selectable text-line density, font-specific menu highlight centering
    1.
    There is a new "Setup/Set Line Spacing" menu option.
    This allows selection between...
    DENSE = 14 text lines in menu
    MEDIUM = 12 text lines in menu
    SPARSE = 10 text lines in menu
    The menu system adjusts accordingly.
    The MEDIUM is actually quite nice, and perhaps should be the default in future.
    2.
    The highlight line for current menu item is now adusted slightly on a per-font basis.
    This allows the inconsistencies in vertical positioning of the fonts to be catered
    for and the menu line is now much better centered for the SMALL CAPS font.
    KNOWN BUGS
    1. When the main menu is on 2 pages, the text/line colour of the 2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
    [PlusCart.asm, flash.c, global.h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]
2020-11-26 More work on the line spacing and communication -> 2600
    * new ZP var 'lineCounter' counts lines in the kernel for use in menu navigation
    The easiest way seemed to be to just manage the variable in the kernel, such that
    at the end of every frame it has the correct number of lines on the menu/screen.
    This value is used when you press UP in menu navigation. If at the top already
    (line 0) then UP takes you to the previous page AND the last line on that page.
    COuld not use the #elements on page from online value, as that is incorrect for
    the last page which is truncated. Although a bit of a 'hack' in that it's not
    as elegant as it could be, this solution works well enough.
    The idea of UP goi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
    [PlusCart.asm, flash.c, global.h]
2020-12-02 new Version for new backend API route with user/device settings
2020-12-02 (re)fixed the corrupt wifi character on page 1
    Code seems to have reverted somehow.
    I did a diff on a local backup and inserted the changes. All good.
2020-12-04 removed all warnings from project
    Mostly explicit casts to resolve the various warnings generated by compiler.
    Modified the DPCP block-copy loop to remove ambiguity/undefined behaviour
    NOT explicitly checked for all changes -- needs review!
    [cartridge_emulation.c]
2020-12-10 Bug Fix, PlusStore Connect with WiFi Manager Portal
    [global.h]
2020-12-31 Potential buffer overflow on status path fixed
    The path "truncation" code had a potential buffer overflow.
    I've rewritten the code to use the existing buffer instead.
    [main.c]
2020-12-31 Now truncates/shows right-side of ALL status message strings
    In the menu status string, now allows any string to be passed as status
    and the string will be displayed right-justified so that it fits in
    the avaialble space. The avialable space depends on #pages, etc... this
    is correctly calculated at display time to maximise use of status space
    The "..." has been changed to ".." to give an extra character for use
    BUGS
    * Note that the "PlusCart(+) by W.Stubig" is too wide so will show right side
    --> since this is going to be changed anyway it's not an issue
    * The "back-conversion" of %xx seems to be failing for + (and others?)
    so text like "DPC+ Experimental" is missing the +. Will fix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
    [main.c]
2021-01-01 test fix for keyboard "/" handling error
    [main.c]
2021-01-01 Fix for "/" truncation error in keyboard
    [global.h, main.c]
2021-01-01 Fixed keyboard usage, adjusted status bar
    1. Put a TEMPORARY HACK in the "Search ROM" keyboard trap. The problem
    is that the "input_field" buffer is/was not cleared. I tried using
    "inputActive" but this variable too seems to not be correct. For now
    I'm just hard-checking for "Search ROM" in the input_field and if it
    is there, then I'm zapping it. This will be fixed soon, but for now
    this hack leaves everytihing (AFAIK) working correctl.
    2. Adjusted the status bar display of paging information. Rather than
    putting a gap between the page icon and numbers (if required for the
    character glitch fix), I shift the whole lot left one character. This
    looks MUCH better and works really nicel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
    [global.h, main.c]
2021-01-02 Rewrites to save ROM/RAM space
    I've changed a few bits of code to be more efficient and save ROM.
    The character-array 'status_message' is now properly defined to not pad
    with extra characters. It no longer lives in .flash0 as I can't see how
    an array of this type can be placed there.
    In any case, ROM savings almost 1K. Most of the action is in the TV_Mode,
    Line_spacing and Font_style functions/code.
    [global.h, main.c]
2021-01-08 optimisations + menu highlight line
    1. used sprintf in the "System Info" routine for string creation, as
    this uses less ROM
    2. Some modifications to the Glacier Belle font
    3. Fixed 1-pixel glitch on line 4 of menu (BG pixel, left edge)
    [main.c]
2021-01-08 Fixed selectors for font/spacing/mode
    The "selected item" marker was interfering with the strstr subtring search
    and causing issues when selecting items from these menus. Now fixed by
    skipping the first character where the marker was.
    [main.c]
2021-01-09 fixed wording in WiFi Manager Protal
    [esp8266_AT_WiFiManager.h]
2021-01-09 Optimisations. Fix for incorrect menu colour line.
    1) Space optimisations with minor code rewrites. A few hundreds of bytes.
    2) Fixed incorrect colour on page 2, item 1. This was an off-by-one
    error in the menu page generation. Tested with different line spacing, seems
    to be OK now.
    [main.c]
2021-01-11 Display Preferences sub-menu. Font update. status update.
    1) Font/TV Mode/Spacing moved to sub-menu
    2) Minor updates to Glacier Belle. Can you improve on pefection?
    3) The status message fixed for sub-menus WiFi and Display Preferences
    4) Minor word changing to Wifi menu (Wifi Setup --> WiFi Connection)
    [main.c]
2021-01-11 Fixed font display on selection menu
    1) Fonts were not displaying in their own font. Was due to an optimisation
    which just used user_settings.font. Now corrected.
    [main.c]
2021-01-12 changes to line 1419 should fix DPC exit, but it doesn't ! prevent boot init (1024 bytes of zero) for http_request_header, curPath and input_field compute max_romsize according to MCU
    [main.c]
2021-01-12 fixes for DPC and exit emulation. Changed order of CCMRAM variables.
    [cartridge_emulation.c, main.c]
2021-01-19 switches for UnoCart, PlusCart, WiFi and SD-Card without FatFS lib integration
2021-01-27 fixed "go back" error on username entry (or any sub-keyboard) usage
    [main.c]
2021-02-02 Prelim alex_79's menu kernel
    First version using the new "flicker-free" menu.
    This should fix the flashing of P0 on those machines with odd spacing/glitches
    [PlusCart.asm]
2021-02-03 Reworked spacing/screen on preferences changes
    [PlusCart.asm]
2021-02-04 fixed UP in menu to go to last item on previous page
    [PlusCart.asm]
2021-02-04 Update STM Firmware Package V1.24.1 to V1.25.2 HAL Driver v1.7.6 to v1.7.10 and CMSIS v2.6.3 to v2.6.5
2021-02-04 SPI HAL Driver
2021-02-04 Add SPI HAL Driver
2021-02-04 STM32CubeMX code project update
2021-02-04 switches for hardware and periphery
2021-02-06 UnoCart GPIO fix, firmware update from SD-Card
    [main.c]
2021-02-08 fixed not resolved merge conflict.
    [main.c]
2021-02-24 Andrew Davie fix for menu delays (init and joystick up/down)
    [PlusCart.asm]
2021-02-25 reset RIOT at start and after exit emulation
    [PlusCart.asm]
2021-03-02 new header files for RIOT reset
    [PlusCart.asm]
2021-03-02 update STM32CubeIDE to v1.6.0
2021-03-04 fix for flash download of files smaller than MAX_RANGE_SIZE (32 KiB)
    [flash.c]
2021-03-05 fix for new keyboard adds slash to WiFi Password
    [main.c]
2022-01-28 Menu fix, comments, ACE interface version
    [main.c]
2022-06-09 Fix multiple esp8266_at_version build error.
    [esp8266.c]
2022-12-09 Added bus-stuffing error detection and correction to finish out implementation...
    [PlusCart.ioc, cartridge_emulation.c]
2022-12-09 WIP DMA stream for data fetcher copy
2023-01-10 Add E7 Plusrom support. Fix load for 8K E7 roms(eg. Bump 'n' Jump).
    [cartridge_emulation.c, main.c]
2023-01-27 Added Al-Nafuur's WIP KiCad project from https://forums.atariage.com/topic/344287-next-hardware-revision/?do=findComment&comment=5164378
    [unified-smd-pcb.kicad_pcb, unified-smd-pcb.kicad_sch]
2023-02-20 Switch back to HSI
2024-09-01 Remove incomplete DPC+ firmware driver
2024-09-01 AR driver optimization
2024-11-08 Switch Version to 2.3.24
2025-01-14 cleanup and fix PlusROM exit
    [esp8266.c]
2025-01-14 Add device type to PlusStore header
2025-10-18 corrected filename of included in esp8266.c
    the file is named "esp8266_AT_WiFiManager.h" but the file included was
    "esp8266_AT_WifiManager.h"
    the lower-case 'f' in WiFi is a problem for UNIX like systems where
    filenames are case sensitive
    [esp8266.c]
2026-11-07 Load ELF files larger than 96 KiB from flash, v2.3.32
    ELF files bigger than the RAM buffer are written to flash like the big
    bank switching ROMs (offline ROMs are used in place). Code, writable data
    and read only data with relocations are copied to the buffer, read only
    data without relocations stays in flash.
    .bss may use all 64 KiB of CCM RAM, the menu state behind the menu
    entries is saved and restored on exit. Section headers and .bss size are
    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

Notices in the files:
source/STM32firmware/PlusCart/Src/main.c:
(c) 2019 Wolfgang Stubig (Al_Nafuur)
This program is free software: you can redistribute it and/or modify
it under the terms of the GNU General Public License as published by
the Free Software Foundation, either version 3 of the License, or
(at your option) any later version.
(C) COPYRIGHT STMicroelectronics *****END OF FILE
